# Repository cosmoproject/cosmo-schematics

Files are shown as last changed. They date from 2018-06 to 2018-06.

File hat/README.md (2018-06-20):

% RPi B+ Hat

Raspberry Pi B+ Hat
============================

Expansion Board
----------------------------

This is a project template for a 
[Raspberry Pi B+ Hat](https://github.com/raspberrypi/hats).

This base project includes a PCB edge defined according to 
[this specification](https://github.com/raspberrypi/hats/blob/master/hat-board-mechanical.pdf).
Both a thru-hole and a surface mount connector are provided, along with a different
PCB edge for each. Just keep the PCB edge and connector type that you're using for your design
and delete the others.

The component footprints used in this template are [here](https://github.com/xesscorp/RPi_Hat.pretty).

The board outline looks like this:



Using the Template
----------------------------

To use the Raspberry Pi Hat template with the through-hole connector, do the following:

1. Open the schematic. Remove the SMD connector, J1.
2. Generate the schematic netlist.
3. Generate the .cmp file. (The J2 connector will be the only component in it.)
4. Open the PCB. Hover your mouse over the connector and hit **e** to edit it. Select the J1 SMD connector. In the **Move and Place** section of the **Footprint Properties** window, select the **Free** radio button. Then click **OK**. The SMD connector should now be unlocked so it can be removed.
5. Read in the netlist from the schematic. In the **Extra Footprints** section of the **Netlist** dialog window, select the **Delete** radio button. Then click **Read Current Netlist**. The J1 SMD connector should disappear. Then click **Close**.
6. Finally, delete the upper two arcs and the edge of the board outline.

To use the Raspberry Pi Hat template with the SMD connector, do the following:

1. Open the schematic. Remove the through-hole connector, J2.
2. Generate the schematic netlist.
3. Generate the .cmp file. (The J1 connector will be the only component in it.)
4. Open the PCB. Hover your mouse over the connector and hit **e** to edit it. Select the J2 through-hole connector. In the **Move and Place** section of the **Footprint Properties** window, select the **Free** radio button. Then click **OK**. The through-hole connector should now be unlocked so it can be removed.
5. Read in the netlist from the schematic. In the **Extra Footprints** section of the **Netlist** dialog window, select the **Delete** radio button. Then click **Read Current Netlist**. The J2 through-hole connector should disappear. Then click **Close**.
6. Finally, delete the lower two arcs and the edge of the board outline.

(c)2015 XESS Corp.

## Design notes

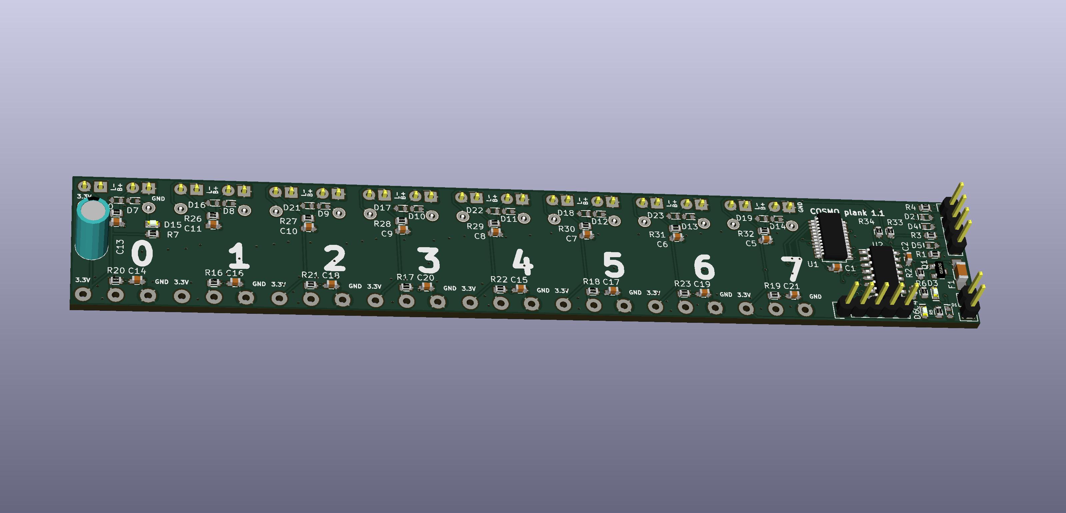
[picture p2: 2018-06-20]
plank/plank-bot.jpg

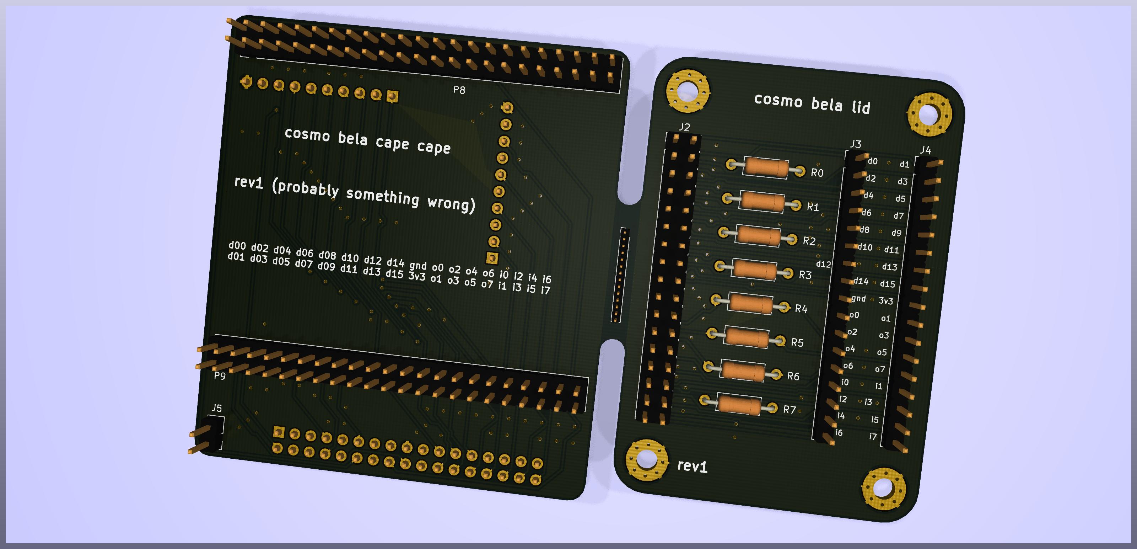
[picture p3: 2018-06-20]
bela-cape2/bela-cape2.jpg

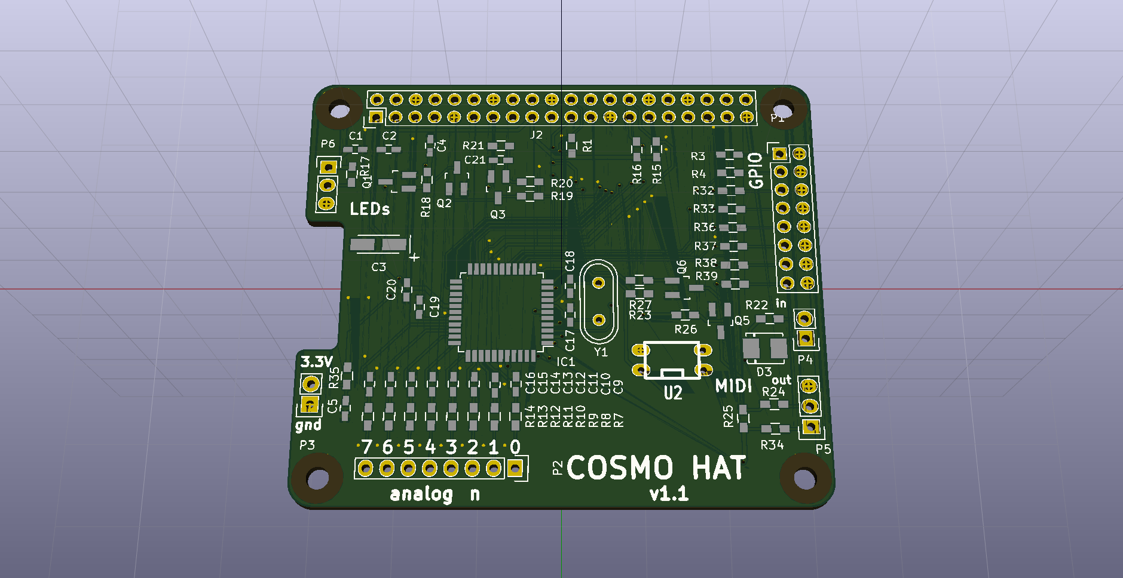
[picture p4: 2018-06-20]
hat/RPi_Hat.png

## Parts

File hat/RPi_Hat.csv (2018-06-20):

Id | Designator | Package | Quantity | Designation | Supplier and ref
1 | J2 | Pin_Header_Straight_2x20 | 1 | RPi_GPIO
2 | ,,, | RPi_Hat_Mounting_Hole | 4
3 | IC1 | TQFP-44_10x10mm_Pitch0.8mm | 1 | ATMEGA1284P-A
4 | SW1 | Pin_Header_Straight_1x03 | 1 | SWITCH_INV
5 | C9,C10,C11,C12,C13,C14,C15,C16,C19,C20,C4 | C_0603_HandSoldering | 11 | 100n
6 | C17,C18 | C_0603_HandSoldering | 2 | 22p
7 | P2,P3 | Pin_Header_Straight_2x08 | 2 | CONN_02X08
8 | R7,R8,R9,R10,R11,R12,R13,R14,R18,R25,R26,R27 | R_0603_HandSoldering | 12 | 10k
9 | R15,R16,R20 | R_0603_HandSoldering | 3 | 4.7k
10 | C21 | C_0603_HandSoldering | 1 | 220p
11 | Q1,Q2,Q3,Q5,Q6 | SOT-23_Handsoldering | 5 | S9013
12 | R17,R23 | R_0603_HandSoldering | 2 | 1k
13 | R19 | R_0603_HandSoldering | 1 | 1.5k
14 | R21 | R_0603_HandSoldering | 1 | 1.1k
15 | D3 | Diode-DO-214BA | 1 | 1N4007
16 | P4 | Pin_Header_Straight_1x02 | 1 | MIDI IN
17 | P5 | Pin_Header_Straight_1x03 | 1 | MIDI OUT
18 | R22,R24,R1,R2,R3,R4,R5,R6,R28,R29,R30,R31,R32,R33,R34 | R_0603_HandSoldering | 15 | 220
19 | P6 | Pin_Header_Straight_1x03 | 1 | ws2812
20 | C1,C2 | C_0603_HandSoldering | 2 | 1u
21 | U2 | dil_4-300 | 1 | LTV-817
22 | C3 | TantalC_SizeA_EIA-3216_HandSoldering | 1 | 10u
23 | Y1 | Crystal_HC49-U_Vertical | 1 | Crystal

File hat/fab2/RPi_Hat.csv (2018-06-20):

Id | Designator | Package | Quantity | Designation | Supplier and ref
1 | J2 | Pin_Header_Straight_2x20 | 1 | RPi_GPIO
2 | ,,, | RPi_Hat_Mounting_Hole | 4
3 | IC1 | TQFP-44_10x10mm_Pitch0.8mm | 1 | ATMEGA1284P-A
4 | C9,C10,C11,C12,C13,C14,C15,C16,C19,C20,C4 | C_0603_HandSoldering | 11 | 100n
5 | C17,C18 | C_0603_HandSoldering | 2 | 22p
6 | R7,R8,R9,R10,R11,R12,R13,R14,R18,R25,R26,R27 | R_0603_HandSoldering | 12 | 10k
7 | R15,R16,R20 | R_0603_HandSoldering | 3 | 4.7k
8 | C21 | C_0603_HandSoldering | 1 | 220p
9 | Q1,Q2,Q3,Q5,Q6 | SOT-23_Handsoldering | 5 | S9013
10 | R17,R23 | R_0603_HandSoldering | 2 | 1k
11 | R19 | R_0603_HandSoldering | 1 | 1.5k
12 | R21 | R_0603_HandSoldering | 1 | 1.1k
13 | D3 | Diode-DO-214BA | 1 | 1N4007
14 | P4 | Pin_Header_Straight_1x02 | 1 | MIDI IN
15 | P5 | Pin_Header_Straight_1x03 | 1 | MIDI OUT
16 | R22,R24,R1,R2,R3,R4,R5,R6,R28,R29,R30,R31,R32,R33,R34,R35,R36,R37,R38,R39 | R_0603_HandSoldering | 20 | 220
17 | P6 | Pin_Header_Straight_1x03 | 1 | ws2812
18 | C1,C2,C5 | C_0603_HandSoldering | 3 | 1u
19 | U2 | dil_4-300 | 1 | LTV-817
20 | C3 | TantalC_SizeA_EIA-3216_HandSoldering | 1 | 10u
21 | Y1 | Crystal_HC49-U_Vertical | 1 | Crystal
22 | P1 | Pin_Header_Straight_2x08 | 1 | GPIO
23 | P2 | Pin_Header_Straight_1x08 | 1 | ADC
24 | P3 | Pin_Header_Straight_1x02 | 1 | APWR

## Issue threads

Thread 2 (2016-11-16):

Pots are reversed

lossius, 2016-11-16:
When testing pots with planch.py, it seems like the diagram for soldering pots have polarity reversed. As a consequence the pots have 0 to right and 1023 to left.

berntisak, 2016-11-20:
Not sure if it's the schematics or the firmware, but we'll come with a fix soon!

kristofferkoch, 2016-11-22:
After https://github.com/cosmoproject/cosmohat-fw/commit/952b4da3fc5b6c0ef5cb0cf31f265e98df75f7ad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, it can now be changed in the config file.

Set zero=1023, and full=0, and you should be good to go.

berntisak, 2016-11-24:
The schematics where also reversed. Have updated them now.

On 22 November 2016 at 20:33, Kristoffer Ellersgaard Koch <
notifications@github.com> wrote:

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

--
Mvh.

Bernt Isak Wærstad

Closed 2016-11-22.

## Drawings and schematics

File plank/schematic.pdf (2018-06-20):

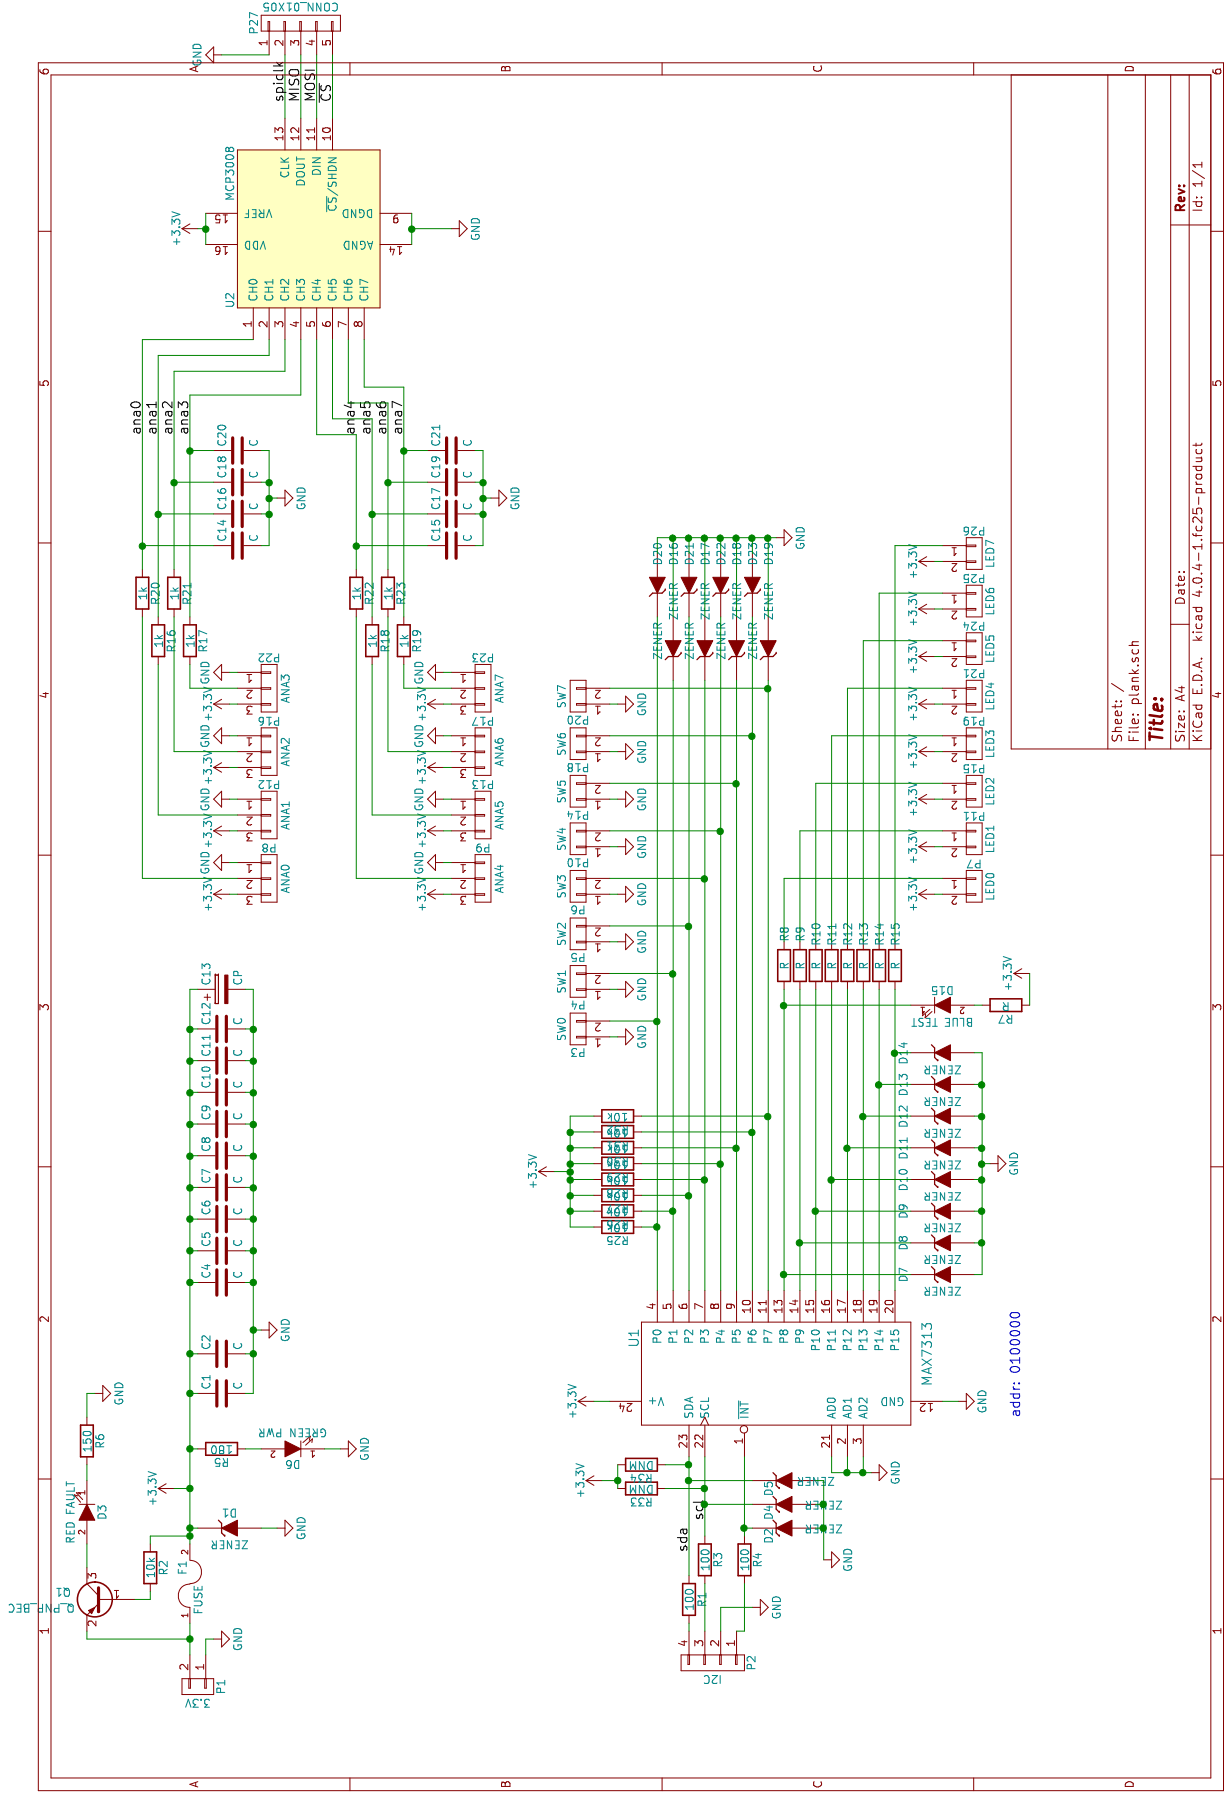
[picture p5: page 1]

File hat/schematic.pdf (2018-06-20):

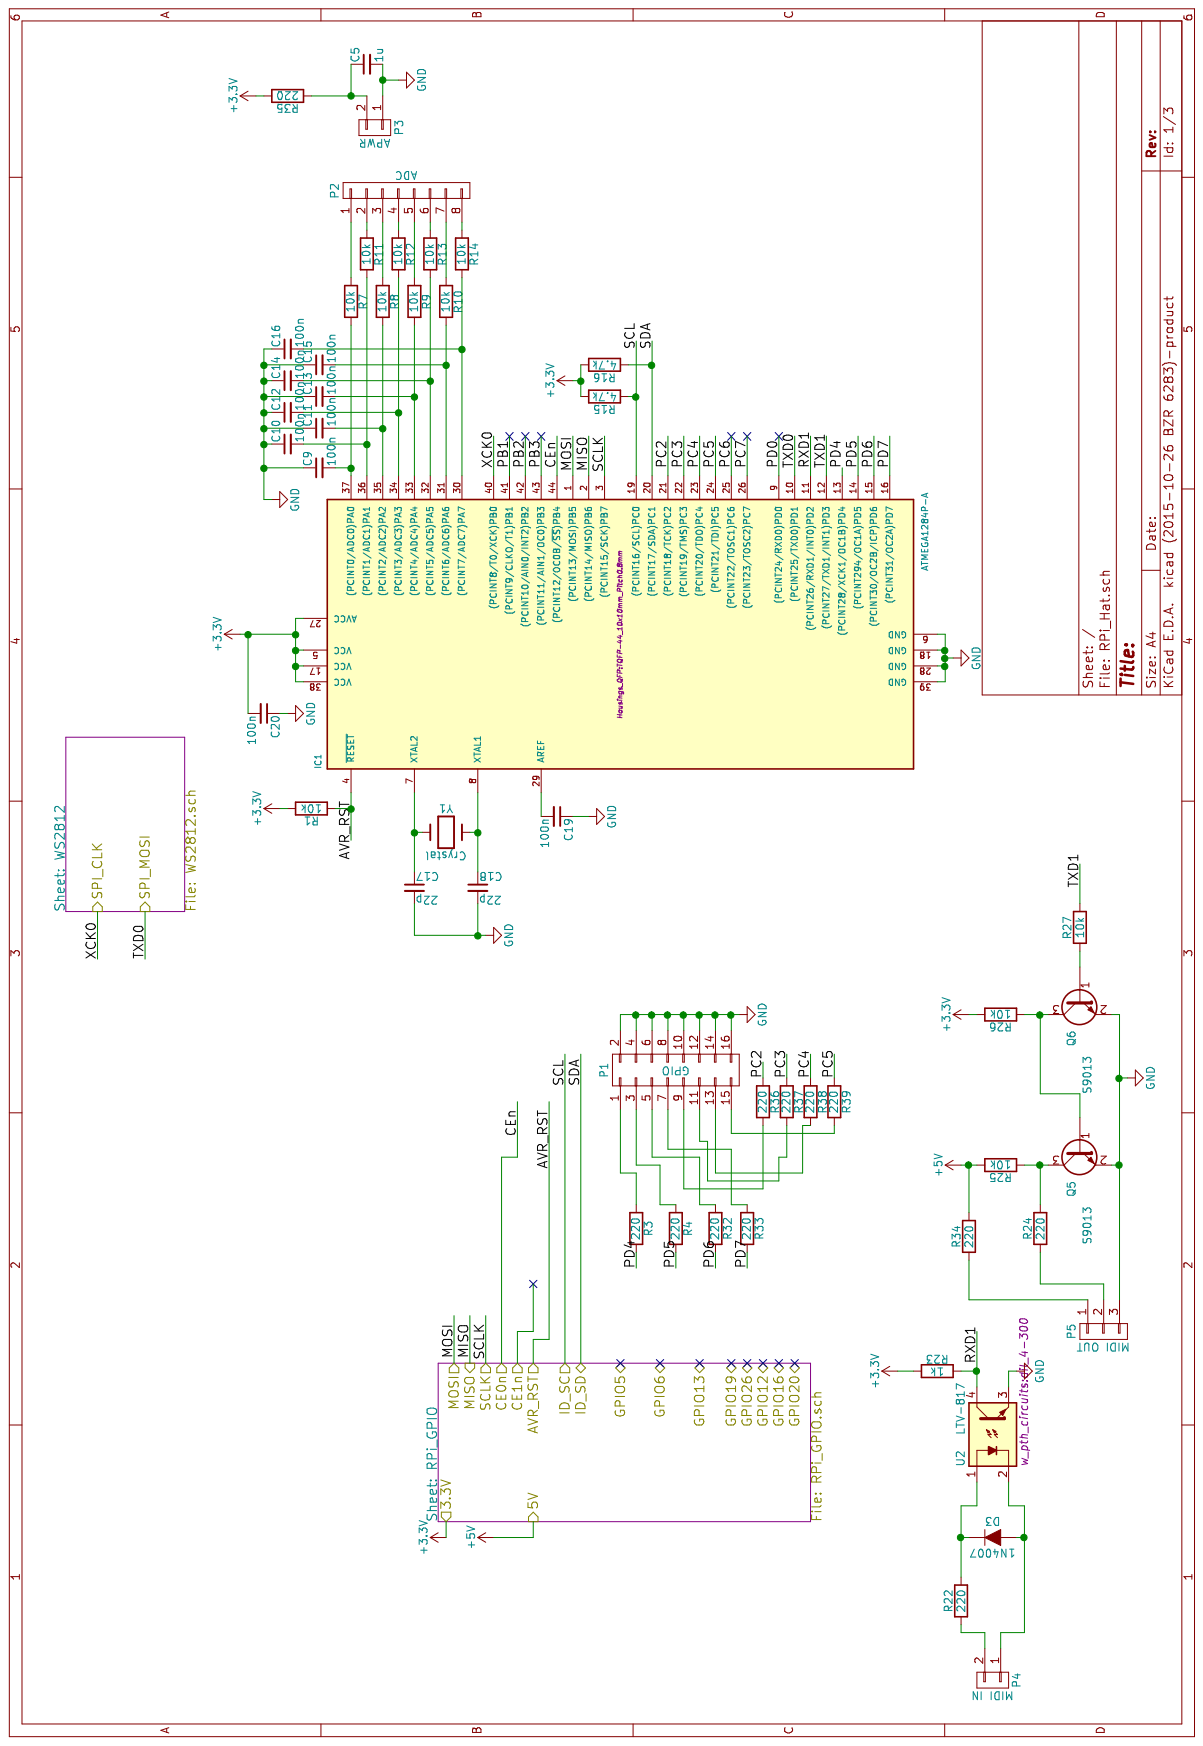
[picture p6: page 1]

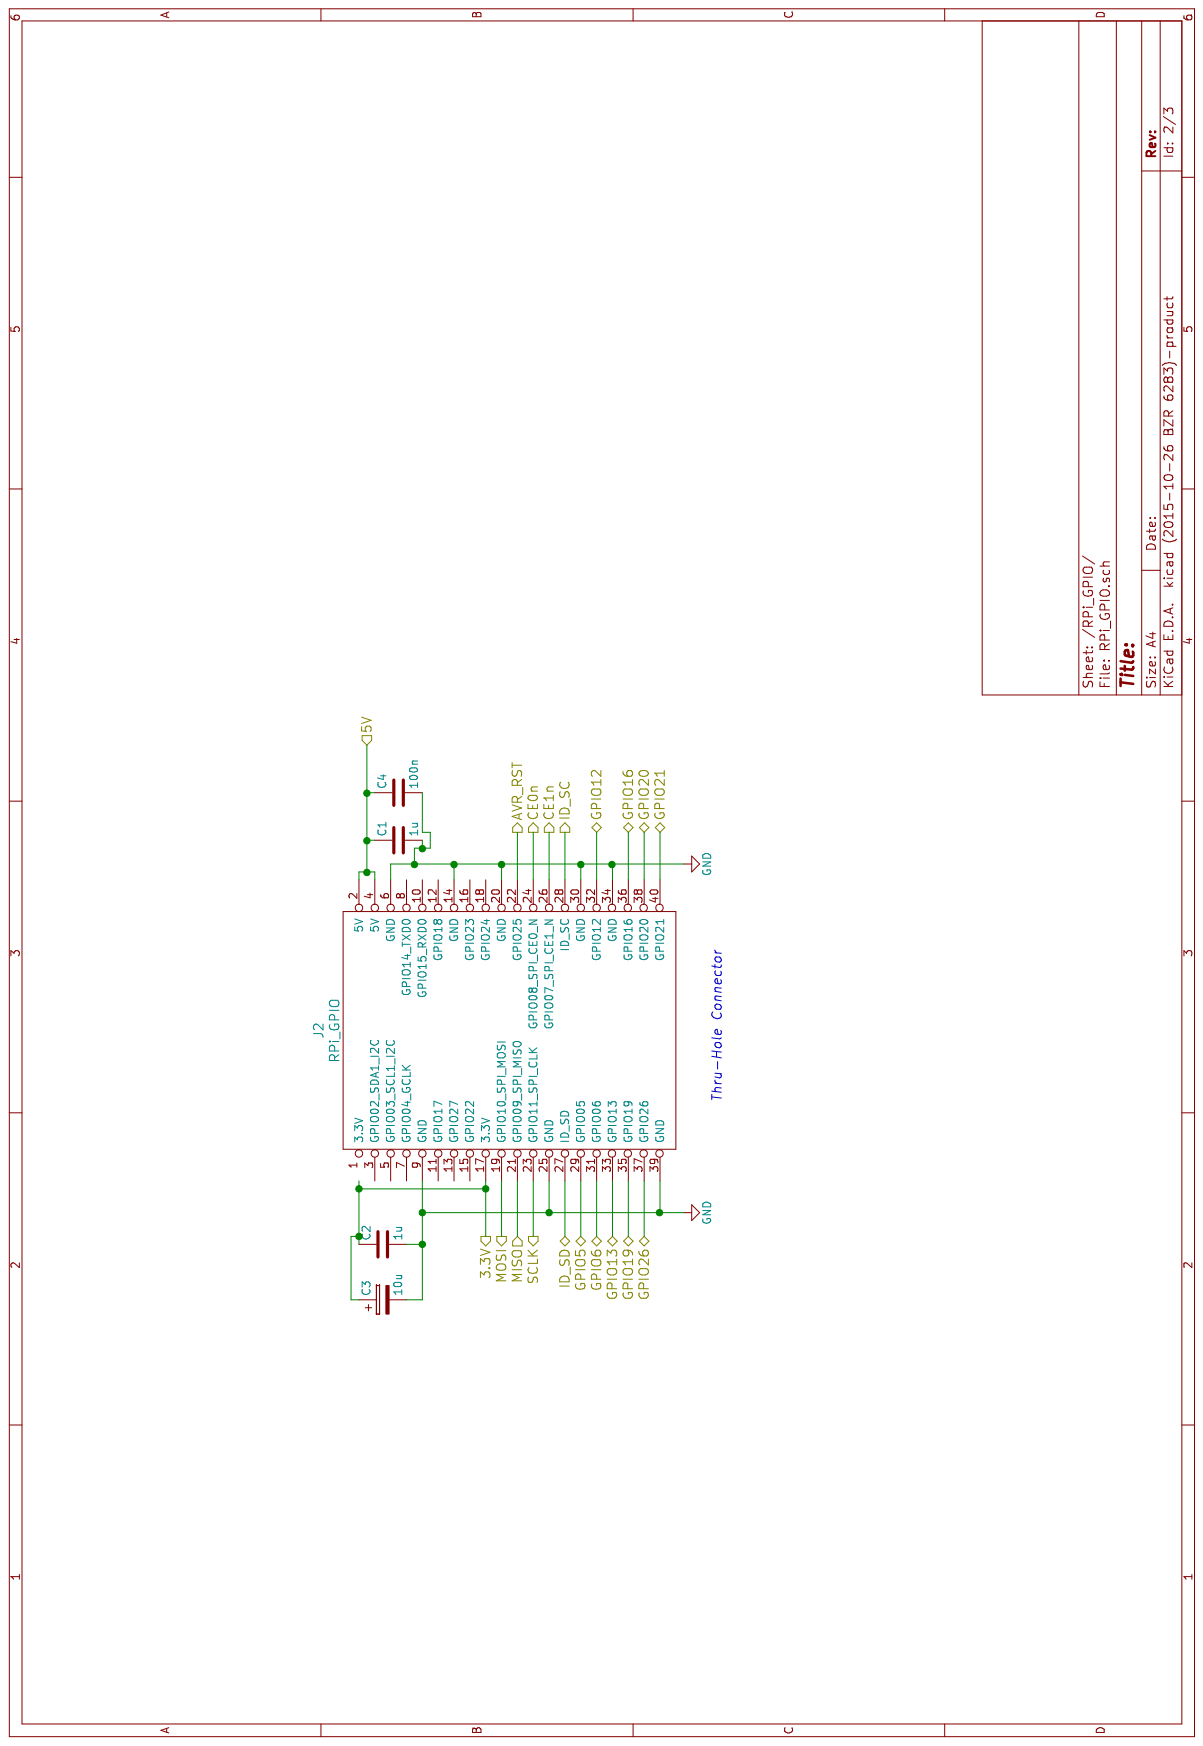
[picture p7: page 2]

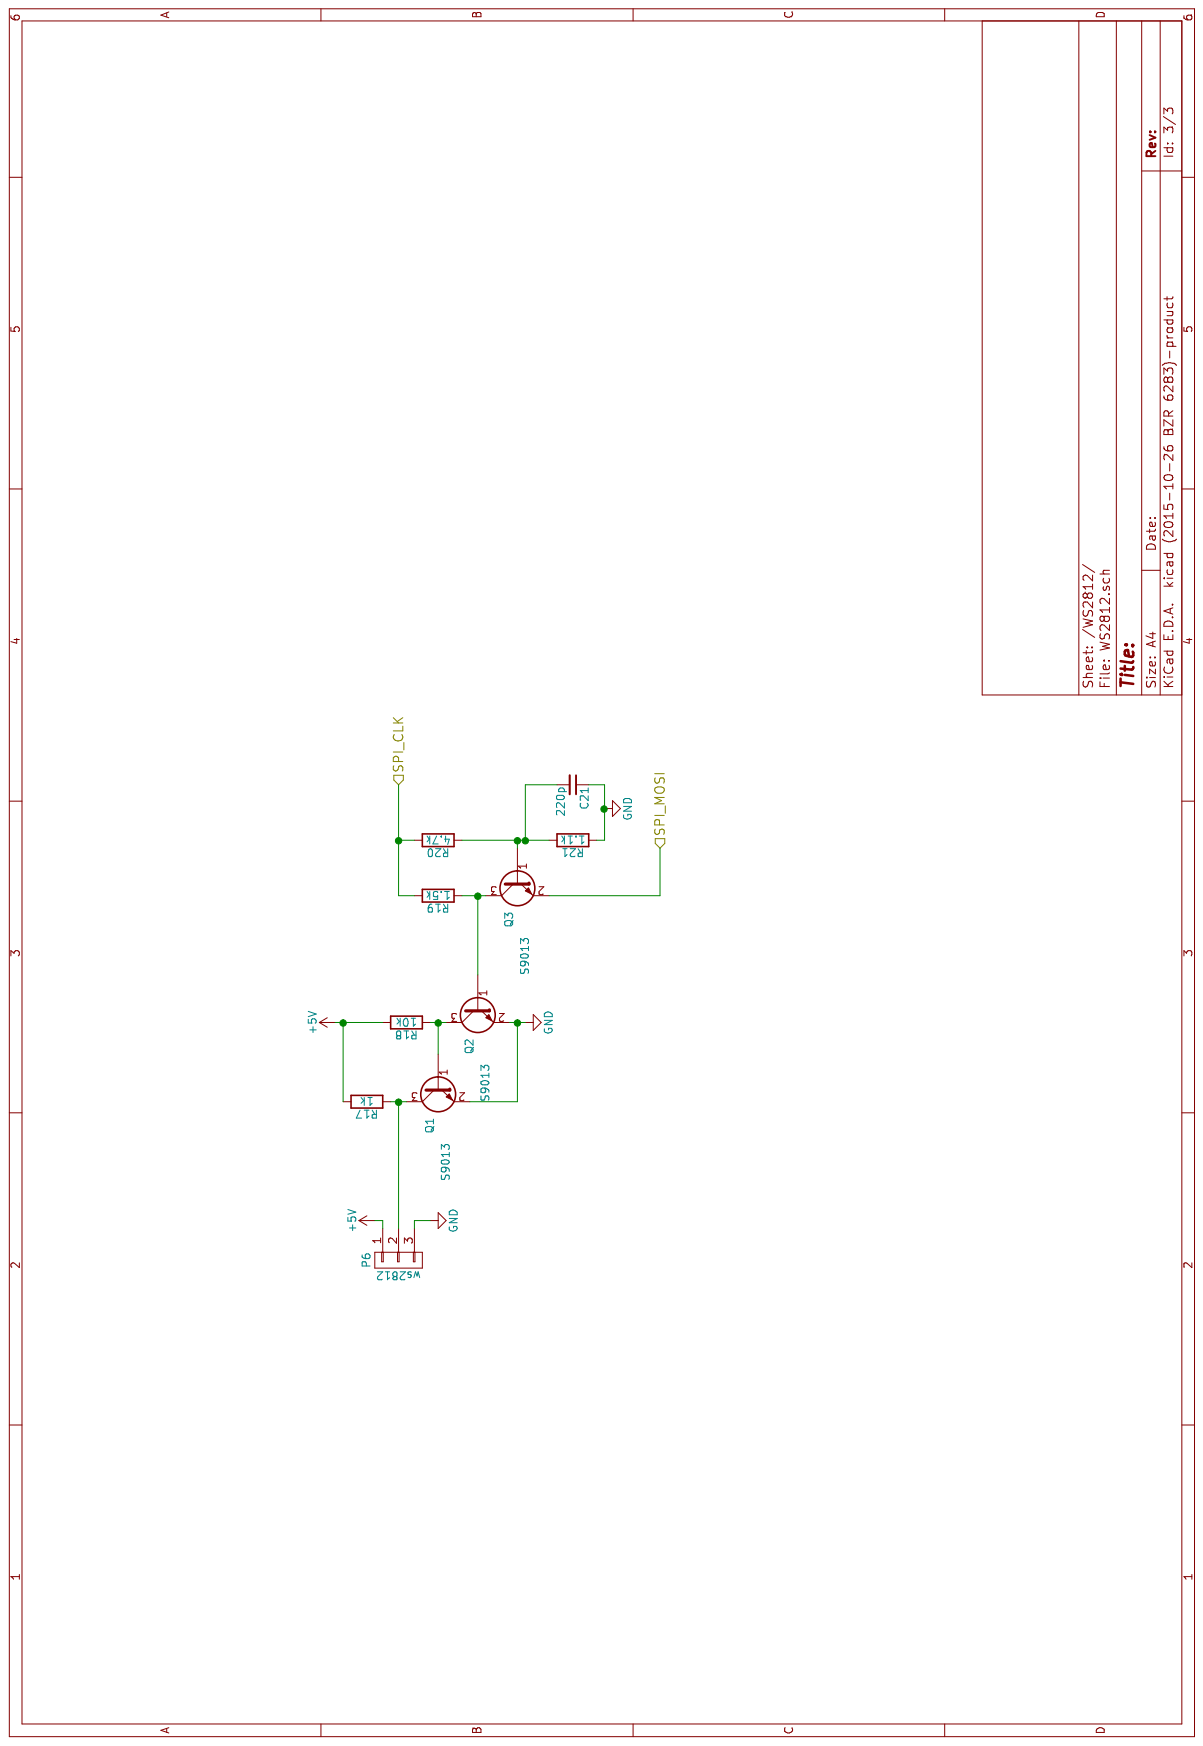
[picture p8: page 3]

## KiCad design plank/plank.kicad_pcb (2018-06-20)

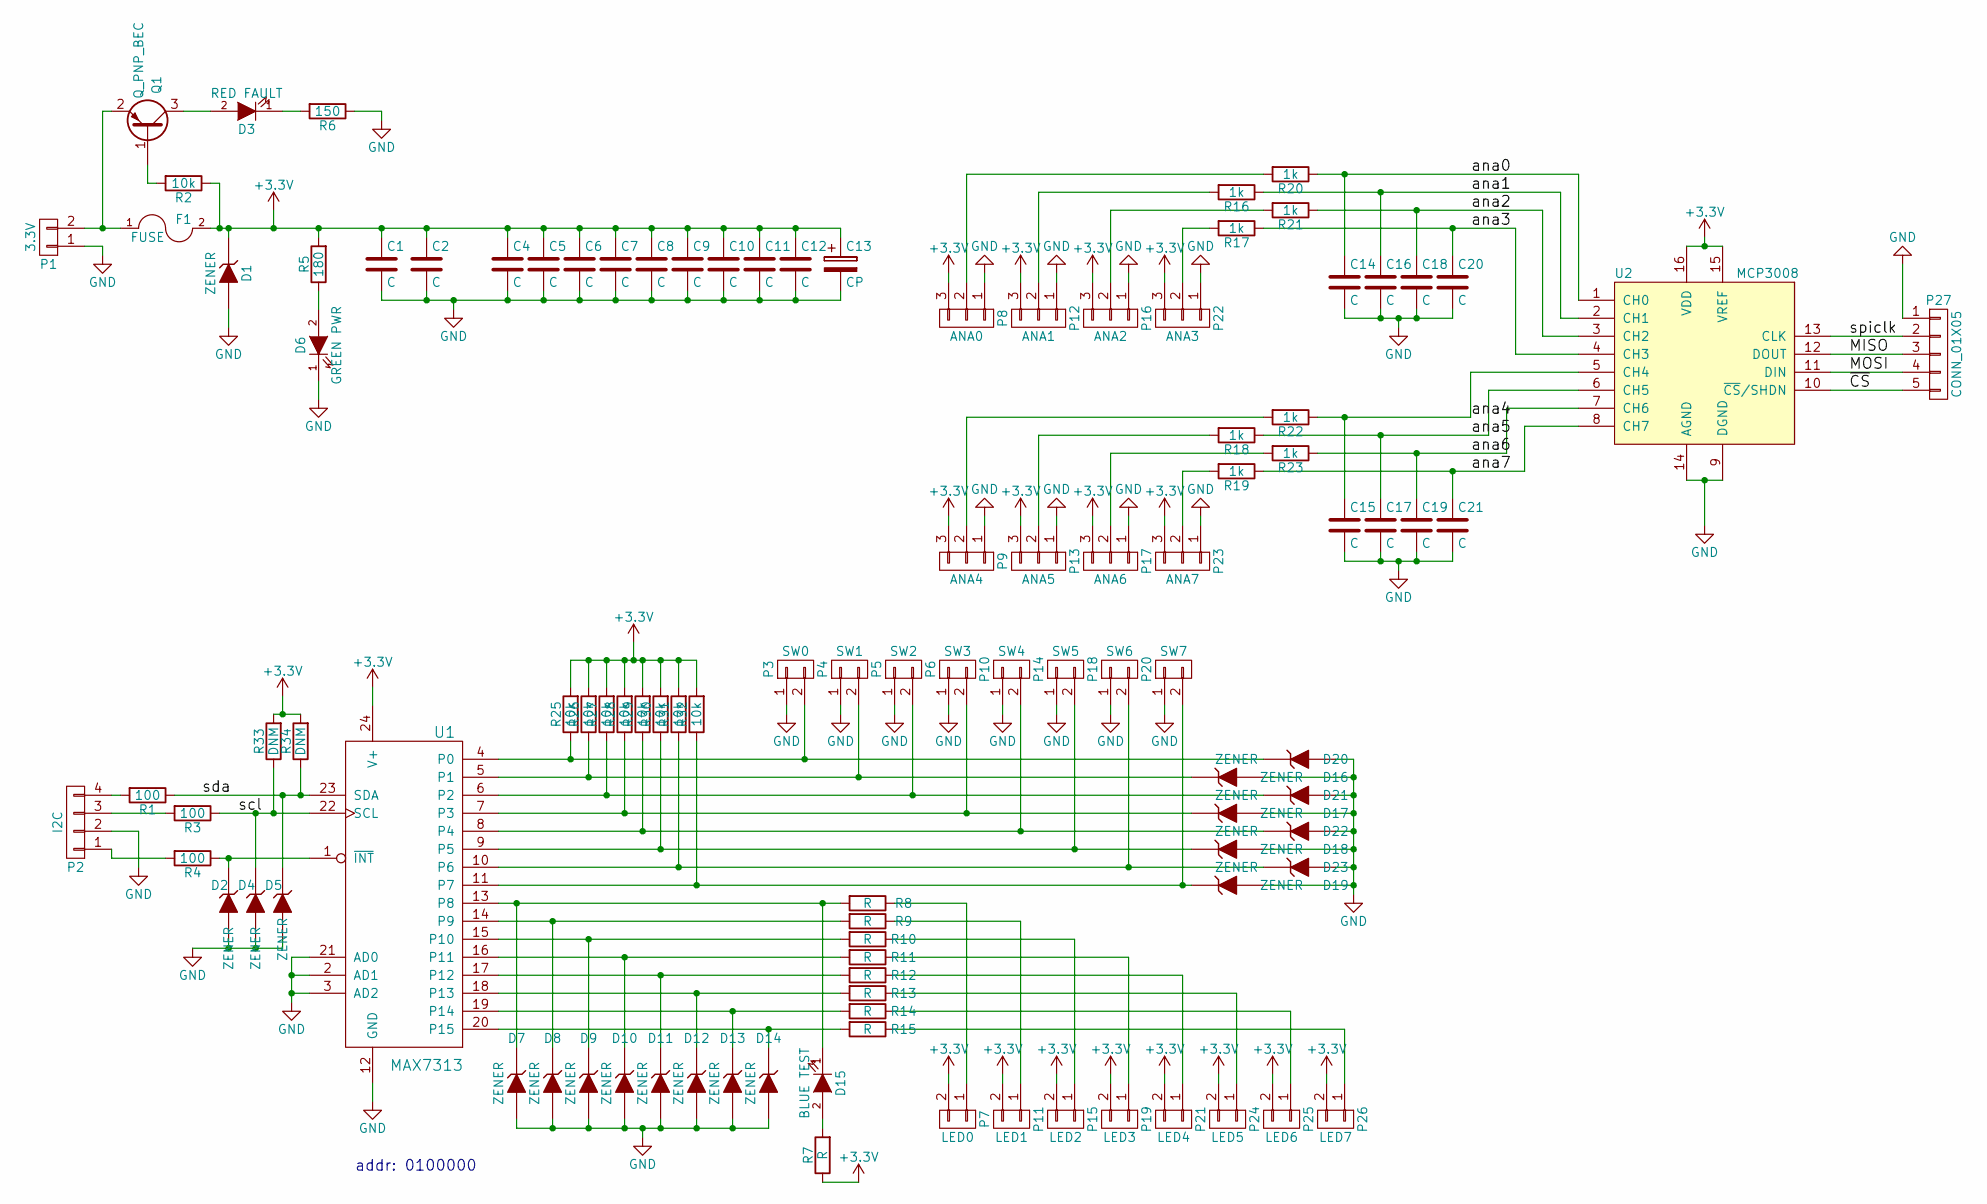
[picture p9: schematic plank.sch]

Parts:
C1, C2, C4, C5, C6, C7, C8, C9, C10, C11, C12, C14, C15, C16, C17, C18, C19, C20, C21: C; C_0603
C13: CP; C_Radial_D5_L11_P2.5
D1, D2, D4, D5, D7, D8, D9, D10, D11, D12, D13, D14, D16, D17, D18, D19, D20, D21, D22, D23: ZENER; SOD-523
D3: RED FAULT; LED_0603
D6: GREEN PWR; LED_0603
D15: BLUE TEST; LED_0603
F1: FUSE; C_1206_HandSoldering
P1: 3.3V; Pin_Header_Straight_1x02
P2: I2C; Pin_Header_Straight_1x04
P3: SW0; Pin_Header_Straight_1x02
P4: SW1; Pin_Header_Straight_1x02
P5: SW2; Pin_Header_Straight_1x02
P6: SW3; Pin_Header_Straight_1x02
P7: LED0; Pin_Header_Straight_1x02
P8: ANA0; Potentiometer_WirePads
P9: ANA4; Potentiometer_WirePads
P10: SW4; Pin_Header_Straight_1x02
P11: LED1; Pin_Header_Straight_1x02
P12: ANA1; Potentiometer_WirePads
P13: ANA5; Potentiometer_WirePads
P14: SW5; Pin_Header_Straight_1x02
P15: LED2; Pin_Header_Straight_1x02
P16: ANA2; Potentiometer_WirePads
P17: ANA6; Potentiometer_WirePads
P18: SW6; Pin_Header_Straight_1x02
P19: LED3; Pin_Header_Straight_1x02
P20: SW7; Pin_Header_Straight_1x02
P21: LED4; Pin_Header_Straight_1x02
P22: ANA3; Potentiometer_WirePads
P23: ANA7; Potentiometer_WirePads
P24: LED5; Pin_Header_Straight_1x02
P25: LED6; Pin_Header_Straight_1x02
P26: LED7; Pin_Header_Straight_1x02
P27: CONN_01X05; Pin_Header_Straight_1x05
Q1: Q_PNP_BEC; SOT-23
R1, R3, R4: 100; R_0603
R2, R25, R26, R27, R28, R29, R30, R31, R32: 10k; R_0603
R5: 180; R_0603
R6: 150; R_0603
R7: R; R_0603
R8, R9, R10, R11, R12, R13, R14, R15: R; Resistor_Horizontal_RM10mm
R16, R17, R18, R19, R20, R21, R22, R23: 1k; R_0603
R33, R34: DNM; R_0603
U1: MAX7313; SSOP-24_3.9x8.7mm_Pitch0.635mm
U2: MCP3008; SOIC-16_3.9x9.9mm_Pitch1.27mm

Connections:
+3V3: C1.1, C2.1, C4.1, C5.1, C6.1, C7.1, C8.1, C9.1, C10.1, C11.1, C12.1, C13.1, D1.1 (K), F1.2, P7.2, P8.3, P9.3, P11.2, P12.3, P13.3, P15.2, P16.3, P17.3, P19.2, P21.2, P22.3, P23.3, P24.2, P25.2, P26.2, R2.1, R5.2, R7.1, R25.2, R26.2, R27.2, R28.2, R29.2, R30.2, R31.2, R32.2, R33.2, R34.2, U1.24 (V+), U2.15 (VREF), U2.16 (VDD)
/MISO: P27.3, U2.12 (DOUT)
/MOSI: P27.4, U2.11 (DIN)
/ana0: C14.1, R20.1, U2.1 (CH0)
/ana1: C16.1, R16.1, U2.2 (CH1)
/ana2: C18.1, R21.1, U2.3 (CH2)
/ana3: C20.1, R17.1, U2.4 (CH3)
/ana4: C15.1, R22.1, U2.5 (CH4)
/ana5: C17.1, R18.1, U2.6 (CH5)
/ana6: C19.1, R23.1, U2.7 (CH6)
/ana7: C21.1, R19.1, U2.8 (CH7)
/scl: D4.1 (K), R3.1, R33.1, U1.22 (SCL)
/sda: D5.1 (K), R1.1, R34.1, U1.23 (SDA)
/spiclk: P27.2, U2.13 (CLK)
/~CS: P27.5, U2.10 (~CS~/SHDN)
GND: C1.2, C2.2, C4.2, C5.2, C6.2, C7.2, C8.2, C9.2, C10.2, C11.2, C12.2, C13.2, C14.2, C15.2, C16.2, C17.2, C18.2, C19.2, C20.2, C21.2, D1.2 (A), D2.2 (A), D4.2 (A), D5.2 (A), D6.1 (K), D7.2 (A), D8.2 (A), D9.2 (A), D10.2 (A), D11.2 (A), D12.2 (A), D13.2 (A), D14.2 (A), D16.2 (A), D17.2 (A), D18.2 (A), D19.2 (A), D20.2 (A), D21.2 (A), D22.2 (A), D23.2 (A), P1.1, P2.2, P3.1, P4.1, P5.1, P6.1, P8.1, P9.1, P10.1, P12.1, P13.1, P14.1, P16.1, P17.1, P18.1, P20.1, P22.1, P23.1, P27.1, R6.1, U1.2 (AD1), U1.3 (AD2), U1.12 (GND), U1.21 (AD0), U2.9 (DGND), U2.14 (AGND)
unnamed: D2.1 (K), R4.1, U1.1 (~INT)
unnamed: D3.1 (K), R6.2
unnamed: D3.2 (A), Q1.3 (C)
unnamed: D6.2 (A), R5.1
unnamed: D8.1 (K), R9.2, U1.14 (P9)
unnamed: D9.1 (K), R10.2, U1.15 (P10)
unnamed: D10.1 (K), R11.2, U1.16 (P11)
unnamed: D11.1 (K), R12.2, U1.17 (P12)
unnamed: D12.1 (K), R13.2, U1.18 (P13)
unnamed: D13.1 (K), R14.2, U1.19 (P14)
unnamed: D14.1 (K), R15.2, U1.20 (P15)
unnamed: D7.1 (K), D15.1 (K), R8.2, U1.13 (P8)
unnamed: D15.2 (A), R7.2
unnamed: D16.1 (K), P4.2, R26.1, U1.5 (P1)
unnamed: D17.1 (K), P6.2, R28.1, U1.7 (P3)
unnamed: D18.1 (K), P14.2, R30.1, U1.9 (P5)
unnamed: D19.1 (K), P20.2, R32.1, U1.11 (P7)
unnamed: D20.1 (K), P3.2, R25.1, U1.4 (P0)
unnamed: D21.1 (K), P5.2, R27.1, U1.6 (P2)
unnamed: D22.1 (K), P10.2, R29.1, U1.8 (P4)
unnamed: D23.1 (K), P18.2, R31.1, U1.10 (P6)
unnamed: F1.1, P1.2, Q1.2 (E)
unnamed: P2.1, R4.2
unnamed: P2.3, R3.2
unnamed: P2.4, R1.2
unnamed: P7.1, R8.1
unnamed: P8.2, R20.2
unnamed: P9.2, R22.2
unnamed: P11.1, R9.1
unnamed: P12.2, R16.2
unnamed: P13.2, R18.2
unnamed: P15.1, R10.1
unnamed: P16.2, R21.2
unnamed: P17.2, R23.2
unnamed: P19.1, R11.1
unnamed: P21.1, R12.1
unnamed: P22.2, R17.2
unnamed: P23.2, R19.2
unnamed: P24.1, R13.1
unnamed: P25.1, R14.1
unnamed: P26.1, R15.1
unnamed: Q1.1 (B), R2.2

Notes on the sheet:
addr: 0100000

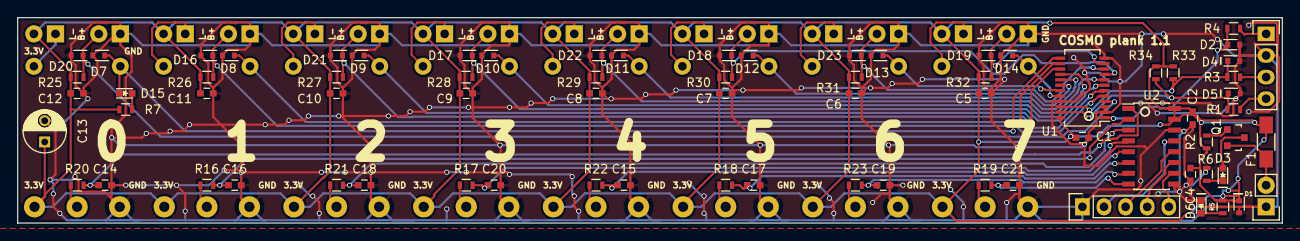
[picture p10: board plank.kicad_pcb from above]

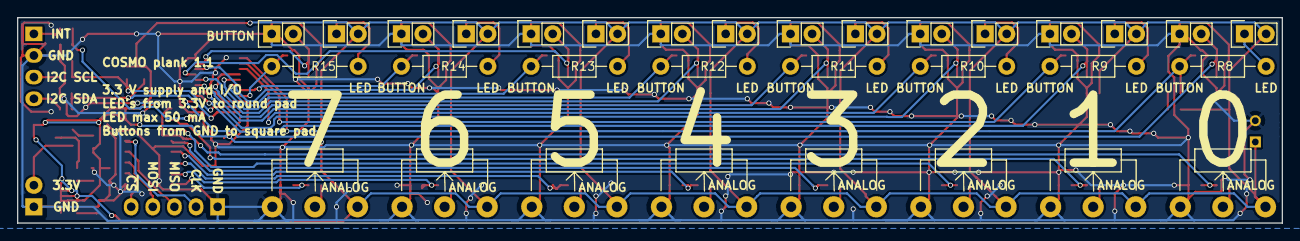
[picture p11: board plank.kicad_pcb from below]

Board: 2 copper layers, 148.6 x 24.1 mm, 107 parts (32 on the bottom side), 58 nets.

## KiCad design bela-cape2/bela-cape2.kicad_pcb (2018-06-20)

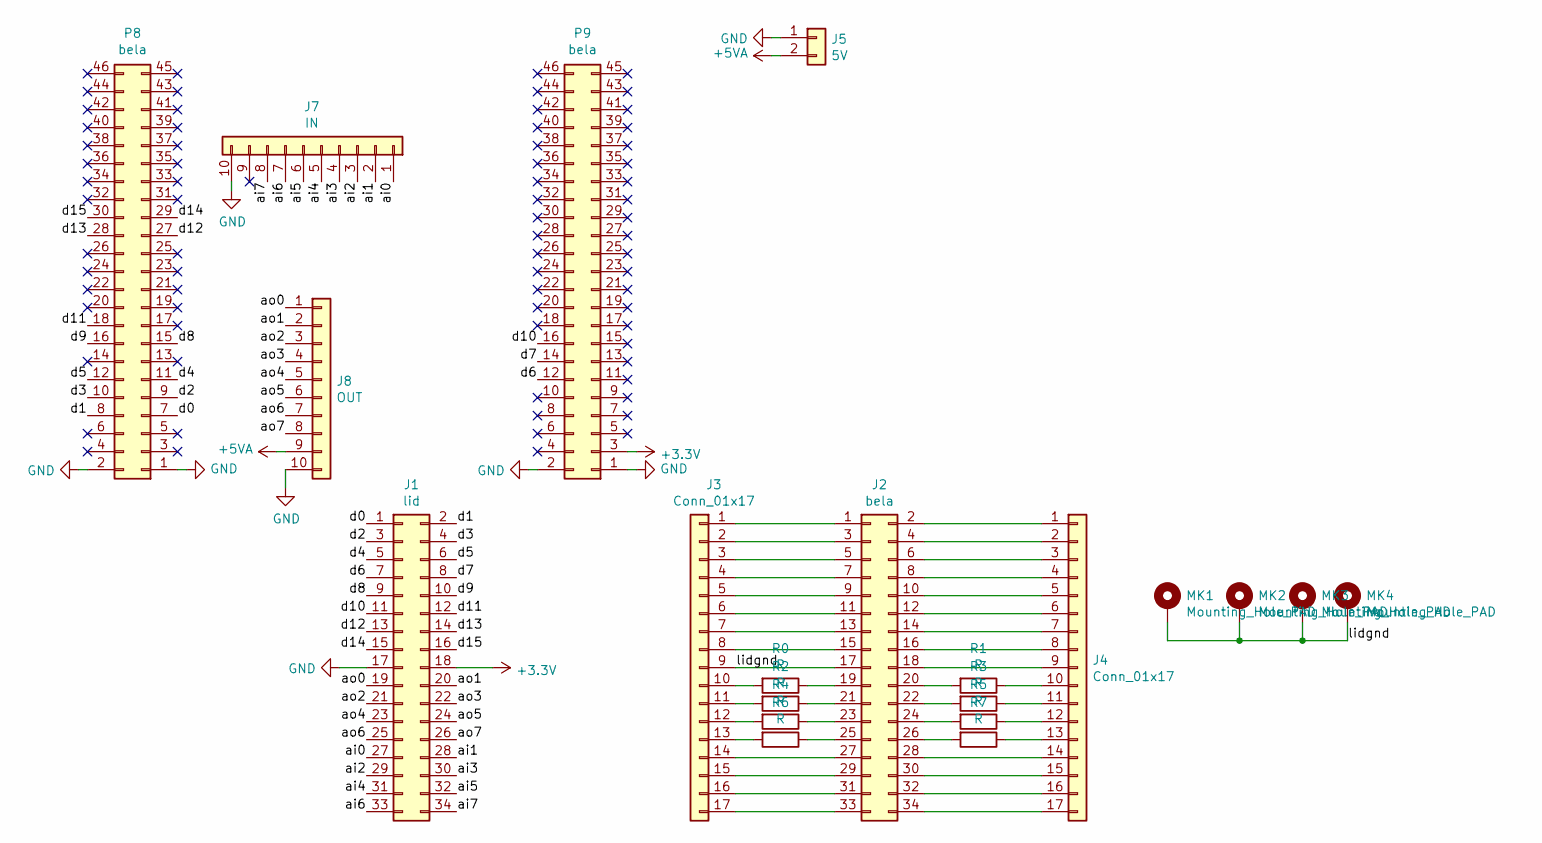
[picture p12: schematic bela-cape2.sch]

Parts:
J1: lid; PinHeader_2x17_P2.54mm_Vertical
J2: bela; PinHeader_2x17_P2.54mm_Vertical
J3, J4: Conn_01x17; PinHeader_1x17_P2.54mm_Vertical
J5: 5V; PinHeader_1x02_P2.54mm_Vertical
J7: IN; PinHeader_1x10_P2.54mm_Vertical
J8: OUT; PinHeader_1x10_P2.54mm_Vertical
MK1, MK2, MK3, MK4: Mounting_Hole_PAD; MountingHole_3.2mm_M3_Pad_Via
P8, P9: bela; PinHeader_2x23_P2.54mm_Vertical
R0, R1, R2, R3, R4, R5, R6, R7: R; R_Axial_DIN0207_L6.3mm_D2.5mm_P10.16mm_Horizontal

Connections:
+3V3: J1.18, P9.3
+5VA: J5.2, J8.9
/ai0: J1.27, J7.1
/ai1: J1.28, J7.2
/ai2: J1.29, J7.3
/ai3: J1.30, J7.4
/ai4: J1.31, J7.5
/ai5: J1.32, J7.6
/ai6: J1.33, J7.7
/ai7: J1.34, J7.8
/ao0: J1.19, J8.1
/ao1: J1.20, J8.2
/ao2: J1.21, J8.3
/ao3: J1.22, J8.4
/ao4: J1.23, J8.5
/ao5: J1.24, J8.6
/ao6: J1.25, J8.7
/ao7: J1.26, J8.8
/d0: J1.1, P8.7
/d1: J1.2, P8.8
/d2: J1.3, P8.9
/d3: J1.4, P8.10
/d4: J1.5, P8.11
/d5: J1.6, P8.12
/d6: J1.7, P9.12
/d7: J1.8, P9.14
/d8: J1.9, P8.15
/d9: J1.10, P8.16
/d10: J1.11, P9.16
/d11: J1.12, P8.18
/d12: J1.13, P8.27
/d13: J1.14, P8.28
/d14: J1.15, P8.29
/d15: J1.16, P8.30
/lidgnd: J2.17, J3.9, MK1.1, MK2.1, MK3.1, MK4.1
GND: J1.17, J5.1, J7.10, J8.10, P8.1, P8.2, P9.1, P9.2
unnamed: J2.1, J3.1
unnamed: J2.2, J4.1
unnamed: J2.3, J3.2
unnamed: J2.4, J4.2
unnamed: J2.5, J3.3
unnamed: J2.6, J4.3
unnamed: J2.7, J3.4
unnamed: J2.8, J4.4
unnamed: J2.9, J3.5
unnamed: J2.10, J4.5
unnamed: J2.11, J3.6
unnamed: J2.12, J4.6
unnamed: J2.13, J3.7
unnamed: J2.14, J4.7
unnamed: J2.15, J3.8
unnamed: J2.16, J4.8
unnamed: J2.18, J4.9
unnamed: J2.19, R0.1
unnamed: J2.20, R1.2
unnamed: J2.21, R2.1
unnamed: J2.22, R3.2
unnamed: J2.23, R4.1
unnamed: J2.24, R5.2
unnamed: J2.25, R6.1
unnamed: J2.26, R7.2
unnamed: J2.27, J3.14
unnamed: J2.28, J4.14
unnamed: J2.29, J3.15
unnamed: J2.30, J4.15
unnamed: J2.31, J3.16
unnamed: J2.32, J4.16
unnamed: J2.33, J3.17
unnamed: J2.34, J4.17
unnamed: J3.10, R0.2
unnamed: J3.11, R2.2
unnamed: J3.12, R4.2
unnamed: J3.13, R6.2
unnamed: J4.10, R1.1
unnamed: J4.11, R3.1
unnamed: J4.12, R5.1
unnamed: J4.13, R7.1

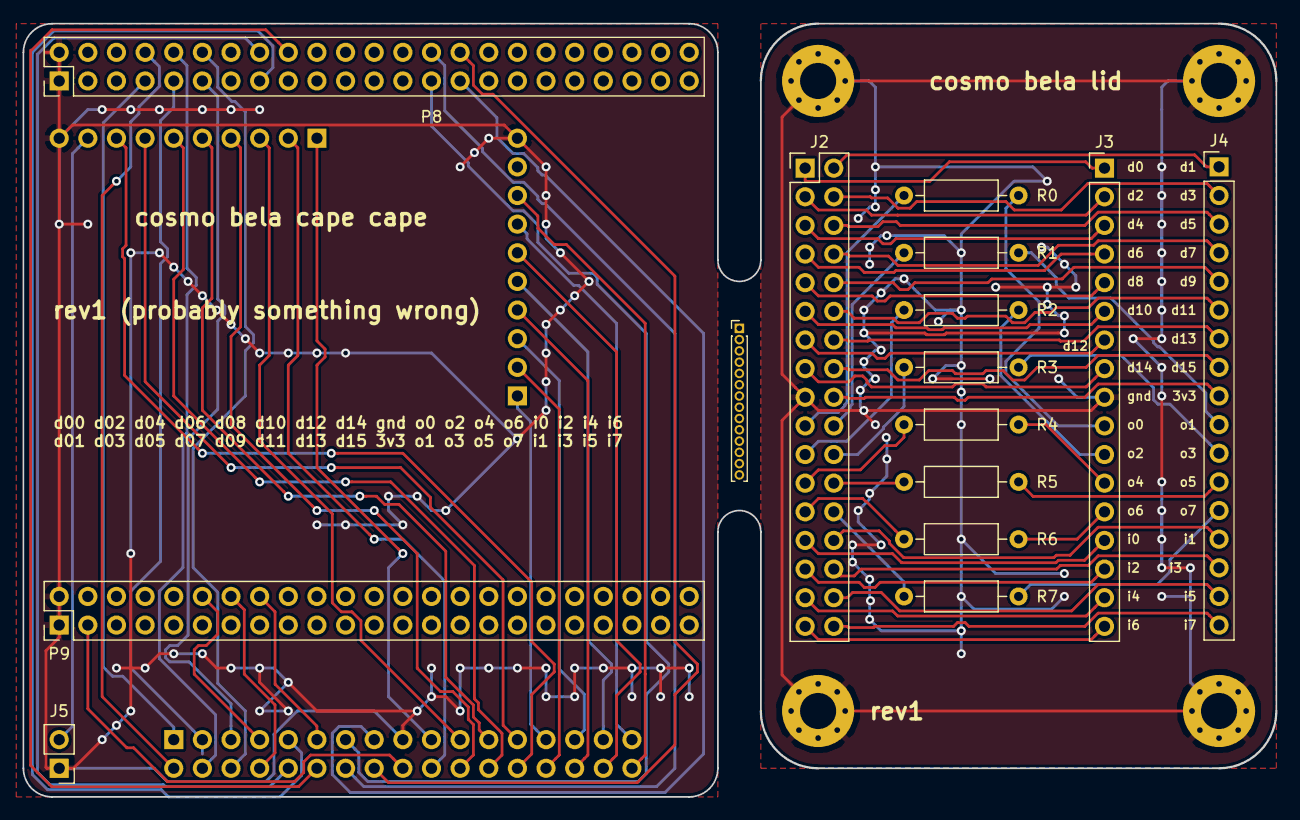
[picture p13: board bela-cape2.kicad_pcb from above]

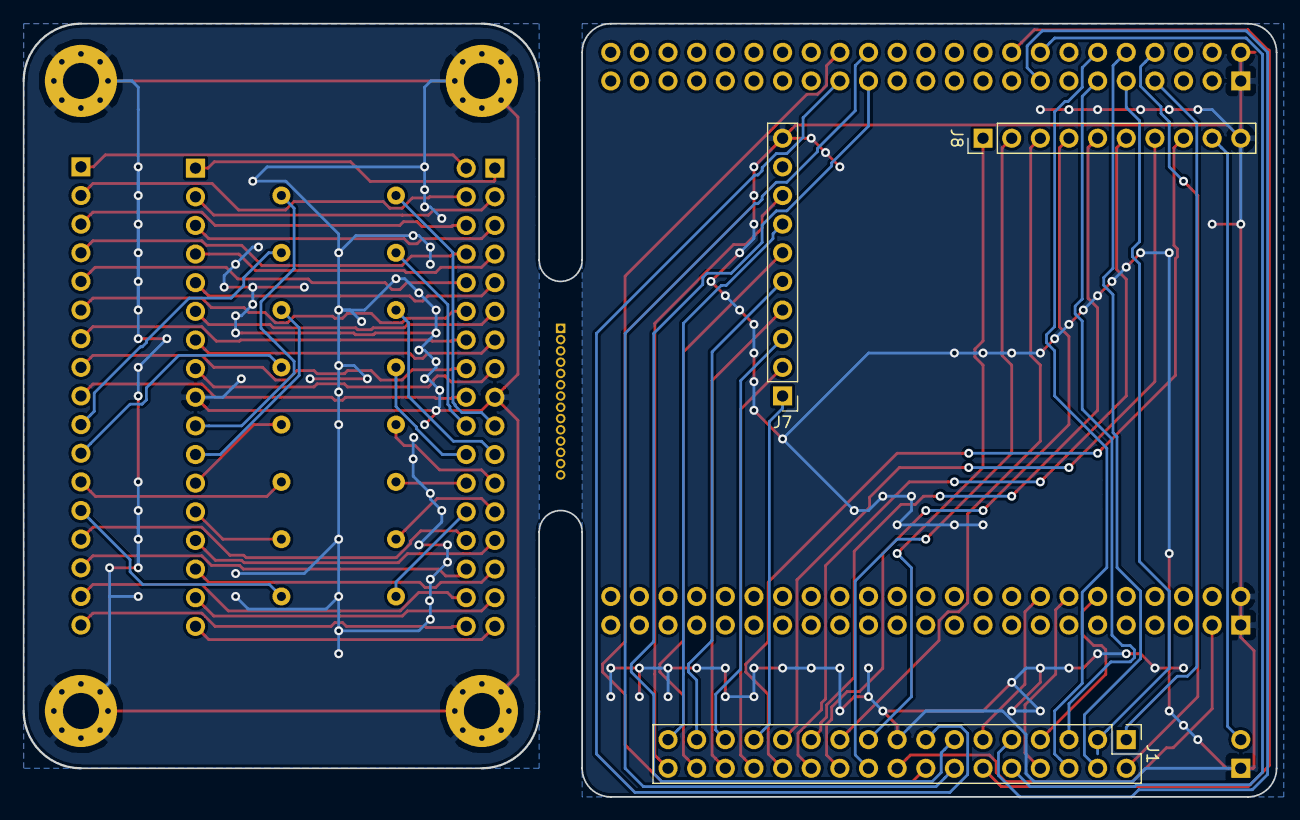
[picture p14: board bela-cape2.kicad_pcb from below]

Board: 2 copper layers, 111.1 x 68.6 mm, 21 parts (3 on the bottom side), 77 nets.

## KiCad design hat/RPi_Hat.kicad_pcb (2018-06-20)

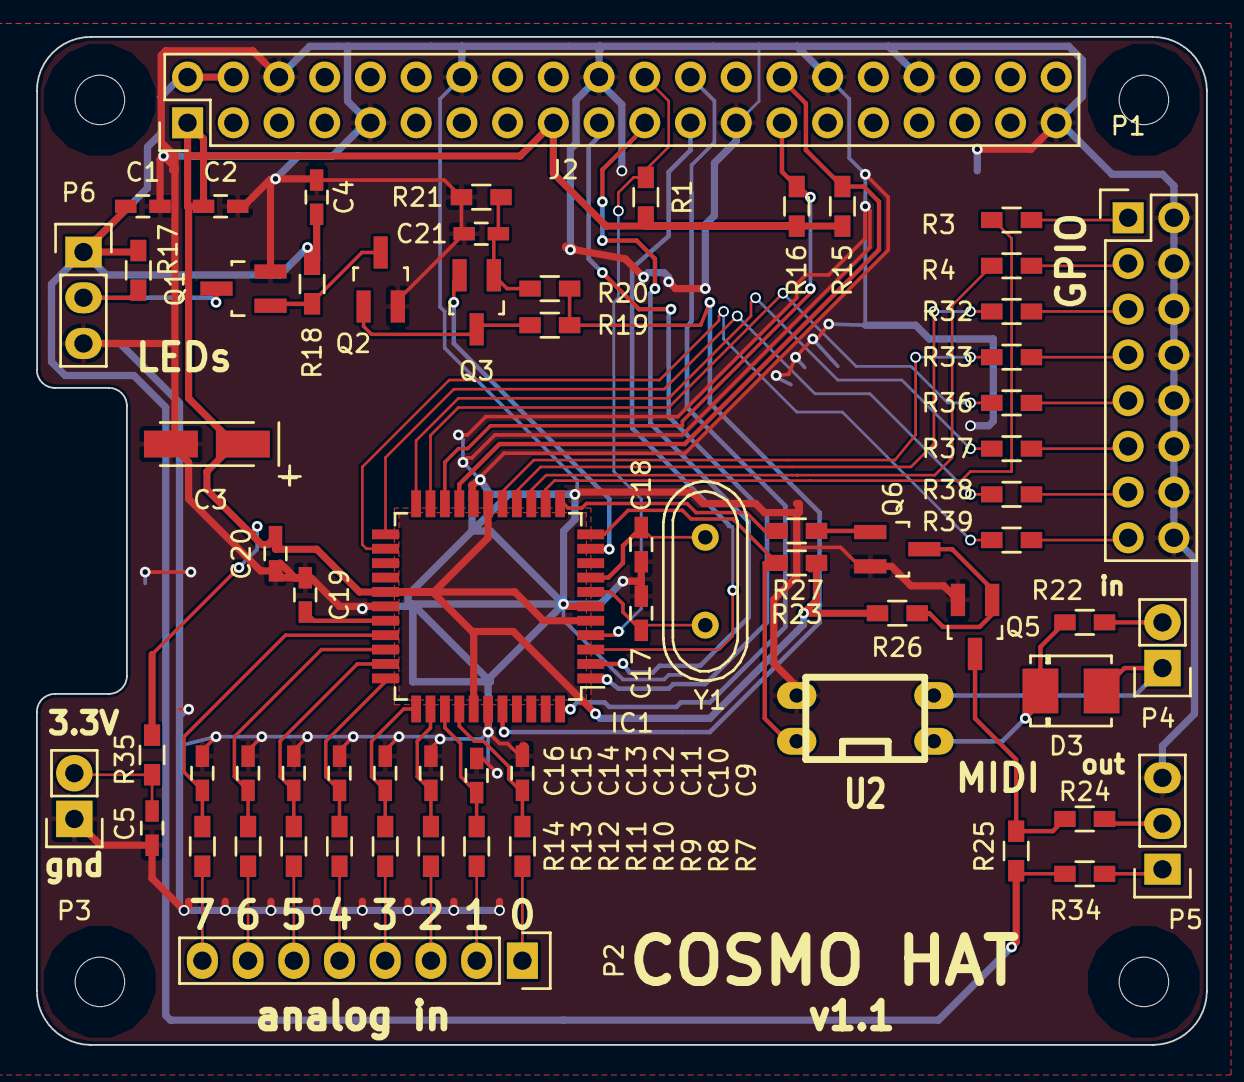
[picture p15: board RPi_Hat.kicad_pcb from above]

Board: 2 copper layers, 65.0 x 56.0 mm, 66 parts (0 on the bottom side), 62 nets.

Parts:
C1, C2, C5: 1u; C_0603_HandSoldering
C3: 10u; TantalC_SizeA_EIA-3216_HandSoldering
C4, C9, C10, C11, C12, C13, C14, C15, C16, C19, C20: 100n; C_0603_HandSoldering
C17, C18: 22p; C_0603_HandSoldering
C21: 220p; C_0603_HandSoldering
D3: 1N4007; Diode-DO-214BA
IC1: ATMEGA1284P-A; TQFP-44_10x10mm_Pitch0.8mm
J2: RPi_GPIO; Pin_Header_Straight_2x20
P1: GPIO; Pin_Header_Straight_2x08
P2: ADC; Pin_Header_Straight_1x08
P3: APWR; Pin_Header_Straight_1x02
P4: MIDI IN; Pin_Header_Straight_1x02
P5: MIDI OUT; Pin_Header_Straight_1x03
P6: ws2812; Pin_Header_Straight_1x03
Q1, Q2, Q3, Q5, Q6: S9013; SOT-23_Handsoldering
R1, R7, R8, R9, R10, R11, R12, R13, R14, R18, R25, R26, R27: 10k; R_0603_HandSoldering
R3, R4, R22, R24, R32, R33, R34, R35, R36, R37, R38, R39: 220; R_0603_HandSoldering
R15, R16, R20: 4.7k; R_0603_HandSoldering
R17, R23: 1k; R_0603_HandSoldering
R19: 1.5k; R_0603_HandSoldering
R21: 1.1k; R_0603_HandSoldering
U2: LTV-817; dil_4-300
Y1: Crystal; Crystal_HC49-U_Vertical

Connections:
+3V3: C2.1, C3.1, C20.2, IC1.5, IC1.17, IC1.27, IC1.38, J2.1, J2.17, R1.2, R15.2, R16.2, R23.1, R26.2, R35.2
+5V: C1.1, C4.1, J2.2, J2.4, P6.1, R17.2, R18.2, R25.2, R34.2
/PC2: IC1.21, R36.1
/PC3: IC1.22, R37.1
/PC4: IC1.23, R38.1
/PC5: IC1.24, R39.1
/PD4: IC1.13, R3.2
/PD5: IC1.14, R4.2
/PD6: IC1.15, R32.2
/PD7: IC1.16, R33.2
/RPi_GPIO/AVR_RST: IC1.4, J2.22, R1.1
/RPi_GPIO/CE0n: IC1.44, J2.24
/RPi_GPIO/ID_SC: IC1.19, J2.28, R15.1
/RPi_GPIO/ID_SD: IC1.20, J2.27, R16.1
/RPi_GPIO/MISO: IC1.2, J2.21
/RPi_GPIO/MOSI: IC1.1, J2.19
/RPi_GPIO/SCLK: IC1.3, J2.23
/RXD1: IC1.11, R23.2, U2.4
/TXD1: IC1.12, R27.2
/WS2812/SPI_CLK: IC1.40, R19.2, R20.2
/WS2812/SPI_MOSI: IC1.10, Q3.2
GND: C1.2, C2.2, C3.2, C4.2, C5.2, C9.1, C10.1, C11.1, C12.1, C13.1, C14.1, C15.1, C16.1, C17.2, C18.2, C19.1, C20.1, C21.1, IC1.6, IC1.18, IC1.28, IC1.39, J2.6, J2.9, J2.14, J2.20, J2.25, J2.30, J2.34, J2.39, P1.2, P1.4, P1.6, P1.8, P1.10, P1.12, P1.14, P1.16, P3.1, P5.3, P6.3, Q1.2, Q2.2, Q5.2, Q6.2, R21.1, U2.3
unnamed: C5.1, P3.2, R35.1
unnamed: C9.2, IC1.37, R7.2
unnamed: C10.2, IC1.36, R11.2
unnamed: C11.2, IC1.35, R8.2
unnamed: C12.2, IC1.34, R12.2
unnamed: C13.2, IC1.33, R9.2
unnamed: C14.2, IC1.32, R13.2
unnamed: C15.2, IC1.31, R10.2
unnamed: C16.2, IC1.30, R14.2
unnamed: C17.1, IC1.7, Y1.1
unnamed: C18.1, IC1.8, Y1.2
unnamed: C19.2, IC1.29
unnamed: C21.2, Q3.1, R20.1, R21.2
unnamed: D3.1, R22.2, U2.1
unnamed: D3.2, P4.1, U2.2
unnamed: P1.1, R3.1
unnamed: P1.3, R4.1
unnamed: P1.5, R32.1
unnamed: P1.7, R33.1
unnamed: P1.9, R36.2
unnamed: P1.11, R37.2
unnamed: P1.13, R38.2
unnamed: P1.15, R39.2
unnamed: P2.1, R7.1
unnamed: P2.2, R11.1
unnamed: P2.3, R8.1
unnamed: P2.4, R12.1
unnamed: P2.5, R9.1
unnamed: P2.6, R13.1
unnamed: P2.7, R10.1
unnamed: P2.8, R14.1
unnamed: P4.2, R22.1
unnamed: P5.1, R34.1
unnamed: P5.2, R24.1
unnamed: P6.2, Q1.3, R17.1
unnamed: Q1.1, Q2.3, R18.1
unnamed: Q2.1, Q3.3, R19.1
unnamed: Q5.1, Q6.3, R26.1
unnamed: Q5.3, R24.2, R25.1
unnamed: Q6.1, R27.1

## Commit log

2015-04-25 Remove offset for 3d model
    [RPi_Hat.kicad_pcb]
2018-06-20 Move cosmo2 branch files into a master folder
    [RPi_GPIO.sch, RPi_Hat.csv, RPi_Hat.kicad_pcb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]
2018-06-20 Check in bela cape cape
    [bela-cape2-B.Cu.gbl, bela-cape2-B.Mask.gbs, bela-cape2-B.SilkS.gbo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]
2018-06-20 Add plank schematics
    [plank-B.Cu.gbl, plank-B.Mask.gbs, plank-B.SilkS.gbo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]
2018-06-20 Add bypass/crossmixer
    [bypass_crossmix.kicad_pcb, bypass_crossmix.sch]
